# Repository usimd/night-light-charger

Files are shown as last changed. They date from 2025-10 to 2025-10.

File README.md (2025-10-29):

# Night light battery charger

One of our children's night light is battery-operated and does not feature a charging port but requires to open a battery enclosure and charge the batteries with an external charger.

This repo contains a small PCB project that adds a USB-C port for charging the three AA NiMH batteries using the [BQ25172](https://www.ti.com/lit/gpn/bq25172) charging IC. The charge current is adjustable using a potentiometer (up to the max. 800mA) and a dual color LED will indicate if the device is currently charging (red) and once charging has finished (green).

The PCB is fitted into the case of this ANSMANN device (https://shop.ansmann.de/en/cartoon-nachtlicht-maus).

## PCB design preview

This is a rendering of the board (missing a few models)

night-light-charger

## Final implementation

The board fits suprisingly well into the case, I just had to remove maybe $\frac{2}{10} mm$ of the inner wall using a Dremel. Also the position of the USB-C connector is pretty well aligned with the outer wall. The dual LED intensity is strong enough to properly indicate the charging status.

Excuse my poor soldering skills, this is just to give you an impression:

      

## Want one, too?

I usually source parts for not just one unit. The PCB house also delivers at least three pieces as backups. 

If you'd also like to have one of these builds, open an issue in this repo. I will check if I have all parts and the PCB in stock and let you know how much it will cost. 
I have no intent to earn any money from these so I'll calculate the exact price based on my sourcing costs. 
If you're curious, I can share these details upon request in the process.

Payment needs to be done via GitHub sponsoring using a one-time donation. 

This project has been prototyped at [AISLER](https://aisler.net/p/OOQHJCJK).

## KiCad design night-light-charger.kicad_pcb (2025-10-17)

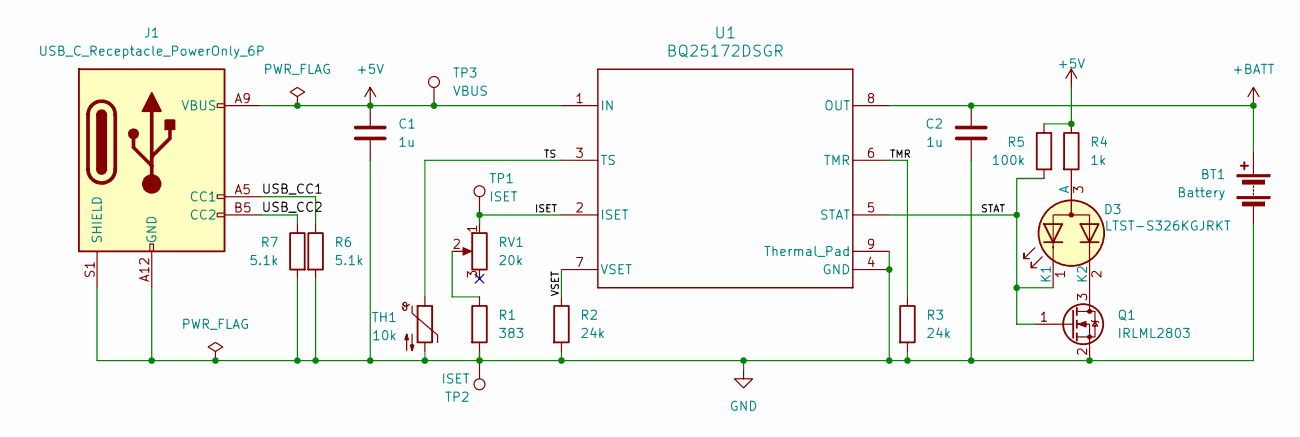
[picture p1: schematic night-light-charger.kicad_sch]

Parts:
BT1: Battery; PinHeader_1x02_P2.54mm_Vertical
C1, C2: 1u; C_0805_2012Metric
D3: LTST-S326KGJRKT; LED_LiteOn_LTST-S326; MPN LTST-S326KGJRKT
J1: USB_C_Receptacle_PowerOnly_6P; USB_C_Receptacle_G-Switch_GT-USB-7010ASV; MPN GT-USB-7010ASV
Q1: IRLML2803; SOT-23; MPN IRLML2803TRPBF
R1: 383; R_0603_1608Metric
R2, R3: 24k; R_0603_1608Metric
R4: 1k; R_0603_1608Metric
R5: 100k; R_0805_2012Metric
R6, R7: 5.1k; R_0402_1005Metric
RV1: 20k; Potentiometer_Bourns_3224W_Vertical; MPN 3224W-1-203E
TH1: 10k; R_Axial_DIN0204_L3.6mm_D1.6mm_P5.08mm_Vertical; MPN MF52A103J3435 (A1)
TP1, TP2: ISET; TestPoint_Pad_D1.0mm
TP3: VBUS; TestPoint_Pad_D1.0mm
U1: BQ25172DSGR; DSG0008A-IPC_A; MPN BQ25172DSGR

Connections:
+5V: C1.1, J1.A9 (VBUS), J1.B9 (VBUS), R4.1, R5.1, TP3.1, U1.1 (IN)
+BATT: BT1.1 (+), C2.1, U1.8 (OUT)
/ISET: RV1.1, TP1.1, U1.2 (ISET)
/STAT: D3.1 (K1), Q1.1 (G), R5.2, U1.5 (STAT)
/TMR: R3.1, U1.6 (TMR)
/TS: TH1.1, U1.3 (TS)
/USB_CC1: J1.A5 (CC1), R6.1
/USB_CC2: J1.B5 (CC2), R7.1
/VSET: R2.1, U1.7 (VSET)
GND: BT1.2 (-), C1.2, C2.2, J1.A12 (GND), J1.B12 (GND), J1.S1 (SHIELD), Q1.2 (S), R1.2, R2.2, R3.2, R6.2, R7.2, TH1.2, TP2.1, U1.4 (GND), U1.9 (Thermal_Pad)
unnamed: D3.3 (A), R4.2
unnamed: D3.2 (K2), Q1.3 (D)
unnamed: R1.1, RV1.2

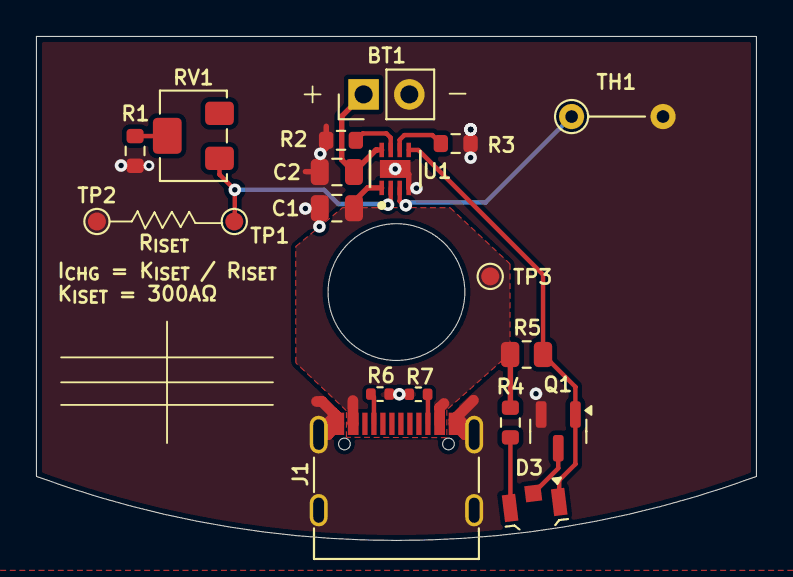
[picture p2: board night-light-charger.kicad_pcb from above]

Board: 2 copper layers, 40.0 x 28.0 mm, 19 parts (0 on the bottom side), 13 nets.
